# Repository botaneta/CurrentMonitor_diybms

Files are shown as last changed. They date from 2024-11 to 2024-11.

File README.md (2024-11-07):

Not tested, Modification of the original project https://github.com/pprasse/diyBMS_CurrentVoltage_ADS1115
----------

# diyBMS_CurrentVoltage_ADS1115

Isolated current and isolated voltage sensor for up to 850V & 200A based on ADS1115 and attiny1614 with isolated RS485 / MODBUS. (based on https://github.com/stuartpittaway/diyBMS-CurrentShunt)

# Current / Voltage measurement

The current measurement uses an ACS758ECB-200B hall-effect based current sensor IC.

The voltage measurement is isolated using an ACPL-C870 Precision Optically Isolated Voltage Sensor.

The analog signal from both measurements are converted using a ADS1115 16 bit ADC.

Coulomb calculation takes place in using an attiny1614 and communication uses isolated RS485 / MODBUS.

# Basis

The project is based on https://github.com/stuartpittaway/diyBMS-CurrentShunt and was created to allow using high voltage batteries for diyBMSv4.

# BOARD

The schematics and board are in the directory KiCad.

# CODE / FIRMWARE

The firmware in the directory code is losely based on Stuard Pittaway's diyBMS CurrentShunt. It uses the same MODBUS RTU registers.

## Coulomb calculation

The charge that goes in and out is calculated by sampling the current 128 times per second using the ADS1115 and measuring the time beween each sample. These are then integrated first to mA*ms (uAs) and then every second to mAh (milliamphours).

## Voltage measurement

The voltage is measured every 1 second as it's irrelevant for charge calculation but interesting for power calculation and over/undervoltage checks.

## MODBUS registers

See [MODBUS Registers.md](./code/MODBUS%20Registers.md)

Maximum compatibililty to diyBMS-CurrentShunt should be maintained to allow using the diyBMS4 ESP32 code unmodified.

Please note that due to compatibility the double registers are in mixed endian (floats compromised of 2 16bit registers in little endian, but individual 16 bit registers are big endian) BUT the 32bit integers are big endian.

Use [read-modbus.sh](./code/read-modbus.sh) ```# code/read-modbus.sh``` to read the modbus registers.

# WARNING

This is a DIY product/solution so don’t use this for safety critical systems or in any situation where there could be a risk to life.  

This board was designed to work with high DC voltages which are notoriously dangerous to work with and are a risk to life. Please make sure you have the appropriate knowledge and always use fuses specified for DC.

There is no warranty, it may not work as expected or at all.

The use of this project is done so entirely at your own risk.  It may involve electrical voltages which could kill - if in doubt, seek help.

The use of this project may not be compliant with local laws or regulations - if in doubt, seek help.

# License

This work is licensed under a Creative Commons Attribution-NonCommercial-ShareAlike 2.0 UK: England & Wales License.

https://creativecommons.org/licenses/by-nc-sa/2.0/uk/

You are free to:
* Share — copy and redistribute the material in any medium or format
* Adapt — remix, transform, and build upon the material
The licensor cannot revoke these freedoms as long as you follow the license terms.

Under the following terms:
* Attribution — You must give appropriate credit, provide a link to the license, and indicate if changes were made. You may do so in any reasonable manner, but not in any way that suggests the licensor endorses you or your use.
* Non-Commercial — You may not use the material for commercial purposes.
* ShareAlike — If you remix, transform, or build upon the material, you must distribute your contributions under the same license as the original.
* No additional restrictions — You may not apply legal terms or technological measures that legally restrict others from doing anything the license permits.

Notices:
You do not have to comply with the license for elements of the material in the public domain or where your use is permitted by an applicable exception or limitation.

No warranties are given. The license may not give you all of the permissions necessary for your intended use. For example, other rights such as publicity, privacy, or moral rights may limit how you use the material.

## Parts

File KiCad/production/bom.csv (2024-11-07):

Designator | Footprint | Quantity | Value | LCSC Part #
_143, _142, _141, _140, _139, _138, _137, _136, _135, _134, _133, _132, _131, _130, _129, _128, _127, _126, _125, _124, _123, _122, _121, _120, _119, _118, _117, _116, _115, _114, _113, _112, _111, _110, _109, _108, _107, _106, _105, _104, _103, _102, _101, _100, _99, _98, _97, _96, _95, _94, _93, _92, _91, _90, _89, _88, _87, _86, _85, _84, _83, _82, _81, _80, _79, _78, _77, _76, _75, _74, _73, _72, _71, _70, _69, _68, _67, _66, _65, _64, _63, _62, _61, _60, _59, _58, _57, _56, _55, _54, _53, _52, _51, _50, _49, _48, _47, _46, _45, _44, _43, _42, _41, _40, _39, _38, _37, _36, _35, _34, _33, _32, _31, _30, _29, _28, _27, _26, _25, _24, _23, _22, _21, _20, _19, _18, _17, _16, _15, _14, _13, _12, _11, _10, _9, _8, _7, _6, _5, _4, _3, _2, |  | 143
C1, C16, C18, C4, C7 | 0805 | 5 | 10u
C10, C8, C9 | 0805 | 3 | 100nF
C11, C12, C13, C14, C15, C17, C2, C26, C3, C5 | 0805 | 10 | 100n
C19 | 1206 | 1 | 1uF
C20 | 0805 | 1 | 100nF 100V
C21 | 0805 | 1 | 1uF
C22, C23 | 0805 | 2 | 10nF
C24 | 0805 | 1 | 3.3nF
C25 | 1210 | 1 | 47uF
C6 | 0805 | 1 | 1n
D1 | D_SMA | 1 | SMAJ5.0A
D2 | 0805 | 1 | GREEN
D3 | 0805 | 1 | RED
D4 | D_SMA | 1 | 400V 1A 1.3V @ 1A 150ns SMA
F1 | 1210 | 1 | Fuse, 0.5A
J1 | PhoenixContact_MSTBA_2,5_3-G-5,08_1x03_P5.08mm_Horizontal | 1 | Screw_Terminal_01x03
J2 | PinHeader_1x11_P2.54mm_Vertical | 1 | Conn_01x11_Pin
J3 | PhoenixContact_MC_1,5_4-G-3.5_1x04_P3.50mm_Horizontal | 1 | Screw_Terminal_01x04
J4 | Wuerth_REDCUBE-THR_WP-THRBU_74650194_THR | 1 | 9x9 PIN connector
J6 | PhoenixContact_MC_1,5_2-G-3.81_1x02_P3.81mm_Horizontal | 1 | Screw_Terminal_01x02
JP1 | SolderJumper-2_P1.3mm_Bridged_Pad1.0x1.5mm | 1 | SolderJumper_2_Bridged
L1 | L_TDK_SLF7045 | 1 | 1mH
PS1 | Converter_DCDC_Murata_MEE1SxxxxSC_THT | 1 | MEE1S0505SC
R1, R10, R11, R18, R2 | 0805 | 5 | 4k7
R12, R13 | 0805 | 2 | 330R
R14 | 0805 | 1 | 470R
R15, R17, R23, R24, R7, R8 | 0805 | 6 | 10K
R16 | 0805 | 1 | 120R
R20 | 0805 | 1 | 680k
R21 | 0805 | 1 | 150k
R22 | 0805 | 1 | 470k
R3, R4, R5 | PP | R_MELF_MMB-0207 | 0805 Compatible | 3 | 402k
R6 | PP _ R_MELF_MMB-0207 _ 0805 Compatible | 1 | 4k7
R9 | 0805 | 1 | 100K
RV1 | Potentiometer_Bourns_3296W_Vertical | 1 | 500
U1 | SSO-8_6.8x5.9mm_P1.27mm_Clearance8mm | 1 | ACPL-C870
U2 | TSSOP-10_3x3mm_P0.5mm | 1 | ADS1115IDGS
U3 | Allegro_CB_PFF | 1 | ACS758xCB-200B-PFF
U4 | SOIC-14_3.9x8.7mm_P1.27mm | 1 | ATtiny1614-SS
U5 | SOIC-16W_7.5x10.3mm_P1.27mm | 1 | ADM2483xRW
U6 | MSOP-8_3x3mm_P0.65mm | 1 | LM5009A

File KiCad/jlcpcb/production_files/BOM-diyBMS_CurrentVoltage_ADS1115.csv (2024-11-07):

Comment | Designator | Footprint | LCSC
100K | R9 | R_0805_2012Metric | C103905
ACPL-C870 | U1 | SSO-8_6.8x5.9mm_P1.27mm_Clearance8mm | C1346335
1uF | C19 | C_1206_3216Metric | C13832
ACS758xCB-200B-PFF | U3 | Allegro_CB_PFF | C163288
10nF | C22,C23 | C_0805_2012Metric | C1710
10K | R15,R17,R23,R24,R7,R8 | R_0805_2012Metric | C17414
120R | R16 | R_0805_2012Metric | C17437
150k | R21 | R_0805_2012Metric | C17470
330R | R12,R13 | R_0805_2012Metric | C17630
4k7 | R1,R10,R11,R18,R2 | R_0805_2012Metric | C17673
470k | R22 | R_0805_2012Metric | C17709
470R | R14 | R_0805_2012Metric | C17710
680k | R20 | R_0805_2012Metric | C17797
GREEN | D2 | LED_0805_2012Metric | C2297
1uF | C21 | C_0805_2012Metric | C28323
10u | C1,C16,C18,C4,C7 | C_0805_2012Metric | C2932476
ADS1115IDGS | U2 | TSSOP-10_3x3mm_P0.5mm | C37593
ADM2483xRW | U5 | SOIC-16W_7.5x10.3mm_P1.27mm | C386280
LM5009A | U6 | MSOP-8_3x3mm_P0.65mm | C477978
ATtiny1614-SS | U4 | SOIC-14_3.9x8.7mm_P1.27mm | C481364
100nF | C10,C8,C9 | C_0805_2012Metric | C49678
MEE1S0505SC | PS1 | Converter_DCDC_Murata_MEE1SxxxxSC_THT | C5183119
3.3nF | C24 | C_0805_2012Metric | C53175
500 | RV1 | Potentiometer_Bourns_3296W_Vertical | C69564
100nF 100V | C20 | C_0805_2012Metric | C696367
Fuse, 0.5A | F1 | Fuse_1210_3225Metric | C720079
47uF | C25 | C_1210_3225Metric | C77101
RED | D3 | LED_0805_2012Metric | C84256
400V 1A 1.3V @ 1A 150ns SMA | D4 | D_SMA | C85103
1mH | L1 | L_TDK_SLF7045 | C91523

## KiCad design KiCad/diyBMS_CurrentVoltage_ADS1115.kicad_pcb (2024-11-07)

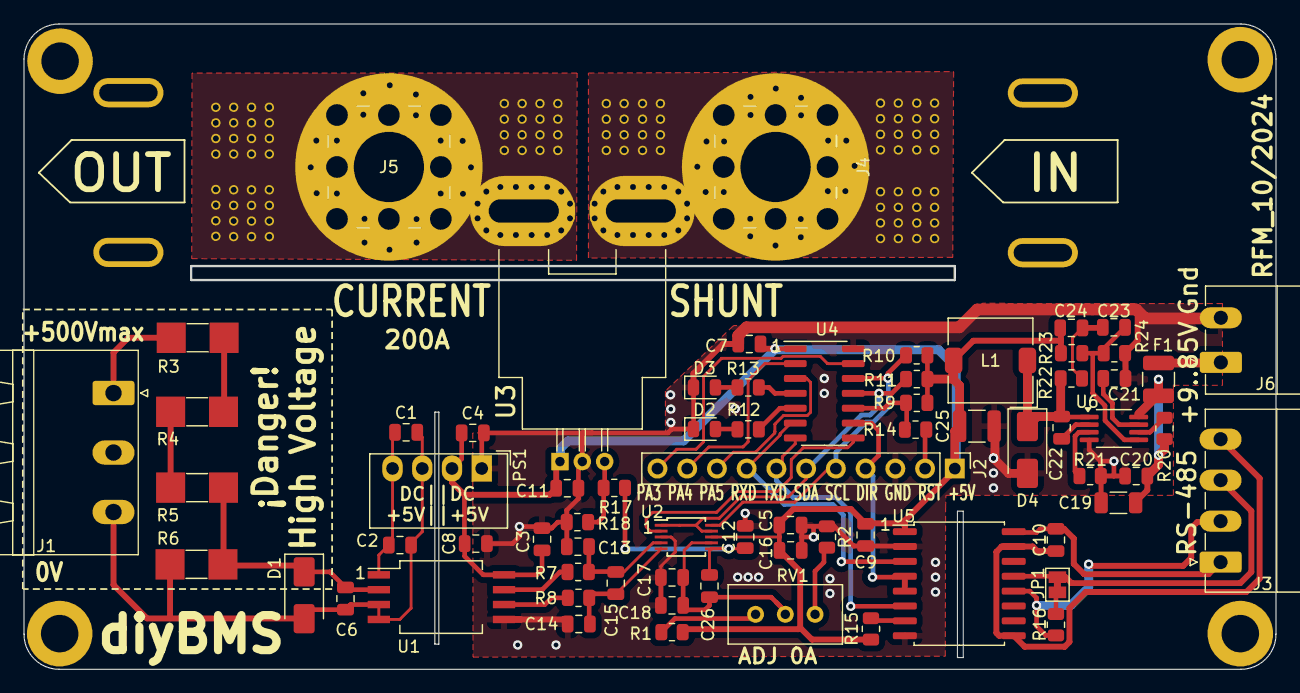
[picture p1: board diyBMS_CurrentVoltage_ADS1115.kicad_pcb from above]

Board: 2 copper layers, 106.9 x 55.1 mm, 70 parts (0 on the bottom side), 49 nets.

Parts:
C1, C4, C7, C16, C18: 10u; C_0805_2012Metric
C2, C3, C5, C11, C12, C13, C14, C15, C17, C26: 100n; C_0805_2012Metric
C6: 1n; C_0805_2012Metric
C8, C9, C10: 100nF; C_0805_2012Metric
C19: 1uF; C_1206_3216Metric
C20: 100nF 100V; C_0805_2012Metric
C21: 1uF; C_0805_2012Metric
C22, C23: 10nF; C_0805_2012Metric
C24: 3.3nF; C_0805_2012Metric
C25: 47uF; C_1210_3225Metric
D1: SMAJ5.0A; D_SMA
D2: GREEN; LED_0805_2012Metric
D3: RED; LED_0805_2012Metric
D4: 400V 1A 1.3V @ 1A 150ns SMA; D_SMA
F1: Fuse, 0.5A; Fuse_1210_3225Metric
J1: Screw_Terminal_01x03; PhoenixContact_MSTBA_2,5_3-G-5,08_1x03_P5.08mm_Horizontal
J2: Conn_01x11_Pin; PinHeader_1x11_P2.54mm_Vertical
J3: Screw_Terminal_01x04; PhoenixContact_MC_1,5_4-G-3.5_1x04_P3.50mm_Horizontal
J4, J5: 9x9 PIN connector; Wuerth_REDCUBE-THR_WP-THRBU_74650194_THR
J6: Screw_Terminal_01x02; PhoenixContact_MC_1,5_2-G-3.81_1x02_P3.81mm_Horizontal
JP1: SolderJumper_2_Bridged; SolderJumper-2_P1.3mm_Bridged_Pad1.0x1.5mm
L1: 1mH; L_TDK_SLF7045
PS1: MEE1S0505SC; Converter_DCDC_Murata_MEE1SxxxxSC_THT
R1, R2, R10, R11, R18: 4k7; R_0805_2012Metric
R3, R4, R5: 402k; PP | R_MELF_MMB-0207 | 0805 Compatible
R6: 4k7; PP _ R_MELF_MMB-0207 _ 0805 Compatible
R7, R8, R17, R23, R24: 10k; R_0805_2012Metric
R9: 100K; R_0805_2012Metric
R12, R13: 330R; R_0805_2012Metric
R14: 470R; R_0805_2012Metric
R15: 10K; R_0805_2012Metric
R16: 120R; R_0805_2012Metric
R20: 680k; R_0805_2012Metric
R21: 150k; R_0805_2012Metric
R22: 470k; R_0805_2012Metric
RV1: 500R; Potentiometer_Bourns_3296W_Vertical
U1: ACPL-C870; SSO-8_6.8x5.9mm_P1.27mm_Clearance8mm
U2: ADS1115IDGS; TSSOP-10_3x3mm_P0.5mm
U3: ACS758xCB-200B-PFF; Allegro_CB_PFF
U4: ATtiny1614-SS; SOIC-14_3.9x8.7mm_P1.27mm
U5: ADM2483xRW; SOIC-16W_7.5x10.3mm_P1.27mm
U6: LM5009A; MSOP-8_3x3mm_P0.65mm

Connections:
+5V: C3.1, C4.1, C5.1, C7.1, C8.1, C9.1, C11.1, C16.2, C24.1, C25.2, J2.1, L1.2, PS1.2 (+Vin), R1.2, R9.2, R10.1, R11.1, R15.1, R23.1, U1.8 (VDD2), U2.8 (VDD), U3.1 (VCC), U4.1 (VCC), U5.1 (VDD1)
+5VP: C1.1, C2.1, PS1.4 (+Vout), U1.1 (VDD1)
A: J3.2, R16.2, U5.12 (A)
ALERT: U2.2 (ALERT/RDY), U4.8 (PB1)
B: J3.3, JP1.2 (B), U5.13 (B)
GND: C3.2, C4.2, C5.2, C7.2, C8.2, C9.2, C11.2, C12.2, C13.1, C14.2, C16.1, C17.2, C18.2, C19.2, C20.2, C21.1, C25.1, D2.1 (K), D3.1 (K), D4.2 (A), J2.3, J6.2, PS1.1 (-Vin), R2.2, R18.2, R21.2, R24.2, U1.5 (GND2), U2.3 (GND), U3.2 (GND), U4.14 (GND), U5.2 (GND1), U5.8 (GND1), U6.4 (RTN)
GND1: C1.2, C2.2, C6.2, D1.2 (A2), J1.3, PS1.3 (-Vout), R6.2, U1.3 (IN-), U1.4 (GND1)
GND2: C10.1, J3.4, U5.9 (GND2), U5.15 (GND2)
unnamed: C23.2, C24.2, R22.2
unnamed: C6.1, D1.1 (A1), R5.2, R6.1, U1.2 (IN)
unnamed: D2.2 (A), R12.1
unnamed: D3.2 (A), R13.1
unnamed: C22.2, D4.1 (K), L1.1, R22.1, U6.1 (SW)
unnamed: J1.1, R3.1
unnamed: J2.2, R14.1
unnamed: J4.1, U3.4 (IP+)
unnamed: J5.1, U3.5 (IP-)
unnamed: F1.2, J6.1
unnamed: JP1.1 (A), R16.1
unnamed: R1.1, RV1.1
unnamed: R2.1, RV1.3
unnamed: R3.2, R4.1
unnamed: R4.2, R5.1
unnamed: R7.1, U1.7 (OUT+)
unnamed: R8.1, U1.6 (OUT-)
unnamed: C13.2, C15.2, R7.2, U2.4 (AIN0)
unnamed: C14.1, C15.1, R8.2, U2.5 (AIN1)
unnamed: C12.1, C26.2, R17.1, U2.6 (AIN2)
unnamed: C17.1, C18.1, C26.1, RV1.2, U2.7 (AIN3)
unnamed: R17.2, R18.1, U3.3 (VIOUT)
unnamed: R15.2, U5.7 (PV)
unnamed: C22.1, U6.2 (BST)
unnamed: C23.1, R23.2, R24.1, U6.5 (FB)
unnamed: R21.1, U6.3 (RCL)
unnamed: R20.2, U6.6 (Rt/SD)
unnamed: C21.2, U6.7 (VCC)
unnamed: C19.1, C20.1, F1.1, R20.1, U6.8 (VIN)
PA3: J2.11, U4.13 (PA3)
PA4: J2.10, U4.2 (PA4)
PA5: J2.9, U4.3 (PA5)
PA6: R13.2, U4.4 (PA6)
PA7: R12.2, U4.5 (PA7)
RESET: R9.1, R14.2, U4.10 (~RESET/PA0)
RXD: J2.8, U4.6 (PB3), U5.3 (RxD)
SCL: J2.5, R10.2, U2.10 (SCL), U4.12 (PA2)
SDA: J2.6, R11.2, U2.1 (ADDR), U2.9 (SDA), U4.11 (PA1)
TXD: J2.7, U4.7 (PB2), U5.6 (TxD)
VDD2: C10.2, J3.1, U5.16 (VDD2)
XDIR: J2.4, U4.9 (PB0), U5.4 (~RE), U5.5 (DE)

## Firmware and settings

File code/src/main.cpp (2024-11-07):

/*
 ____  ____  _  _  ____  __  __  ___    _  _  __
(  _ \(_  _)( \/ )(  _ \(  \/  )/ __)  ( \/ )/. |
 )(_) )_)(_  \  /  ) _ < )    ( \__ \   \  /(_  _)
(____/(____) (__) (____/(_/\/\_)(___/    \/   (_)

DIYBMS V4.0
ISOLATED CURRENT & VOLTAGE MONITORING SYSTEM BASEDO ON ADS1115 / ACS758 / ACPL-C870

(c)2023 Patrick Prasse

based on https://github.com/stuartpittaway/diyBMS-CurrentShunt
(c)2021 Stuart Pittaway

COMPILE THIS CODE USING PLATFORM.IO

LICENSE
Attribution-NonCommercial-ShareAlike 2.0 UK: England & Wales (CC BY-NC-SA 2.0 UK)
https://creativecommons.org/licenses/by-nc-sa/2.0/uk/

* Non-Commercial — You may not use the material for commercial purposes.
* Attribution — You must give appropriate credit, provide a link to the license, and indicate if changes were made.
  You may do so in any reasonable manner, but not in any way that suggests the licensor endorses you or your use.
* ShareAlike — If you remix, transform, or build upon the material, you must distribute your
  contributions under the same license as the original.
* No additional restrictions — You may not apply legal terms or technological measures
  that legally restrict others from doing anything the license permits.

** COMMERCIAL USE AND RESALE PROHIBITED **

*/

// ATTINY1614 (tinyAVR® 1-series of microcontrollers)
// http://ww1.microchip.com/downloads/en/DeviceDoc/ATtiny1614-data-sheet-40001995A.pdf

// MODBUS Protocol
// https://www.ni.com/en-gb/innovations/white-papers/14/the-modbus-protocol-in-depth.html

#if !defined(MODBUSDEFAULTBAUDRATE)
#error MODBUSDEFAULTBAUDRATE must be defined
#endif
#if !defined(MODBUSBASEADDRESS)
#error MODBUSBASEADDRESS must be defined
#endif
#if !defined(MODBUSSERIALCONFIG)
#error MODBUSSERIALCONFIG must be defined
#endif

#include <Arduino.h>
#include <avr/sleep.h>
#include <avr/power.h>
#include <avr/wdt.h>
#include <Wire.h>
#include <EEPROM.h>

#include <FastCRC.h>
#include "debug.h"
#include "ads1115.h"


FastCRC16 CRC16;

#include "main.h"
#include "settings.h"

#include "EmbeddedFiles_Defines.h"

#ifndef SERIALDEBUG
#include "SimpleModbusSlave.h"
#endif

#ifdef SERIALDEBUG
uint32_t lastDebugOutput = 0;
#endif

const uint16_t loop_delay_ms = 2000;

uint32_t milliamphour_out_lifetime = 0;
uint32_t milliamphour_in_lifetime = 0;

uint32_t daily_milliamphour_out = 0;
uint32_t daily_milliamphour_in = 0;

uint32_t milliamphour_out = 0;
uint32_t milliamphour_in = 0;

uint32_t milliamphour_out_offset = 0;
uint32_t milliamphour_in_offset = 0;

uint16_t ModBusBaudRate = MODBUSDEFAULTBAUDRATE;

uint8_t ModbusSlaveAddress = MODBUSBASEADDRESS;

volatile bool config_dirty = false;

uint8_t max_soc_reset_counter = 0;
uint8_t soc_reset_counter = 0;
int32_t last_charge_coulombs = 0;

unsigned long timer = 0;

eeprom_regs registers;

volatile bool wdt_triggered = false;
volatile uint16_t wdt_triggered_count;

void DefaultConfig();


uint16_t CalculateSOC()
{
  double milliamphour_in_scaled = ((double)milliamphour_in / 100.0) * registers.charge_efficiency_factor;
  double milliamphour_batterycapacity = 1000.0 * (uint32_t)registers.batterycapacity_amphour;
  double difference = milliamphour_in_scaled - milliamphour_out;

  double answer = 100 * (difference / milliamphour_batterycapacity);
  if (answer < 0)
  {
    // We have taken more out of the battery than put in, so must be zero SoC (or more likely out of calibration)
    return 0;
  }

  // Add a hard upper limit 655.0%
  if (answer > 655.0)
  {
    answer = 655.0;
  }

  // Store result as fixed point decimal
  uint16_t SOC = 100 * answer;

  return SOC;
}

void ConfigurePorts()
{
  // PA1 = SDA
  // PA2 = SCL
  // PA3 = UNUSED
  // PA4 = UNUSED
  // PA5 = RELAY OUTPUT
  // PA6 = RED LED
  // PA7 = GREEN LED

  // Set pins as Outputs (other pins are inputs)
  PORTA.DIR = GREENLED_PIN_BITMAP | REDLED_PIN_BITMAP | RELAY_PIN_BITMAP;

  // Relay off by default
  PORTA.OUTCLR = RELAY_PIN_BITMAP;

  // Set Port B digital outputs
  // PB0 = XDIR (RS485 transmit enable)
  // PB1 = ALERT
  // PB2 = TX (has to be set as output on tiny1614)
  // PB3 = RX
  // Set pins as Outputs (other pins are inputs)
  PORTB.DIR = PIN0_bm | PIN2_bm;

  PORTB.OUTSET = PIN2_bm; // TX is high

  USART0.CTRLB = USART_RXEN_bm | USART_TXEN_bm; // enable rx and tx
  // Enable interrupts
  sei();
}

void RedLED(bool value)
{
  if (value)
  {
    PORTA.OUTSET = REDLED_PIN_BITMAP;
  }
  else
  {
    PORTA.OUTCLR = REDLED_PIN_BITMAP;
  }
}

void GreenLED(bool value)
{
  if (value)
  {
    PORTA.OUTSET = GREENLED_PIN_BITMAP;
  }
  else
  {
    PORTA.OUTCLR = GREENLED_PIN_BITMAP;
  }
}

void EnableWatchdog()
{
  wdt_triggered = false;

  // Enter protection mode
  CCP = 0xD8;

  // 8 seconds
  WDT.CTRLA = WDT_PERIOD_enum::WDT_PERIOD_8KCLK_gc;

  wdt_reset();
}

/*
void DisableSerial0TX()
{
  //On tiny1614 this saves about 10mA of current
  USART0.CTRLB &= ~(USART_TXEN_bm); // Transmitter Enable bit mask.
}

void EnableSerial0TX()
{
  //When the transmitter is disabled, it will no longer override the TXD pin, and the pin
  //direction is automatically set as input by hardware, even if it was configured as output by the user
  //PB2 as OUTPUT
  PORTB.DIRSET = PIN2_bm;
  USART0.CTRLB |= USART_TXEN_bm; // Transmitter Enable bit mask.
}
*/

void WatchdogTriggered()
{
  // This is the watchdog timer - something went wrong and no serial activity received in over 8 seconds
  wdt_triggered = true;
  wdt_triggered_count++;
}

// pattern is a 32bit pattern to "play" on the RED LED to indicate failure
void __attribute__((noreturn)) blinkPattern(uint32_t pattern)
{
  #ifdef SERIALDEBUG
  Serial.print("blinkPattern=");
  Serial.println(pattern);
  #endif

  // Show the error 4 times
  for (size_t x = 0; x < 4; x++)
  {
    uint32_t p = pattern;

    // Loop through the 32 bits - takes 1024ms in total
    for (size_t i = 0; i < 32; i++)
    {
      wdt_reset();
      if (p & 1)
      {
        RedLED(true);
      }
      else
      {
        RedLED(false);
      }
      p >>= 1;

      // Give user enough time to count the pulses
      delay(200);
    }

    // Switch off LED and wait half second before repeating
    RedLED(false);
    for (size_t i = 0; i < 40; i++)
    {
      wdt_reset();
      delay(50);
    }
  }

  // Both LEDs on whilst we wait for WDT
  RedLED(true);
  GreenLED(true);

  // Finally just hang - this will trigger the watchdog causing a reboot
  delay(100000);
}

// Sets SOC by setting "fake" in/out amphour counts
// value=8212 = 82.12%
void SetSOC(uint16_t value)
{
  // Assume battery is fully charged
  milliamphour_in = 1000 * (uint32_t)registers.batterycapacity_amphour;
  // And we have consumed this much...
  milliamphour_out = (1.0 - ((float)value / 10000.0)) * milliamphour_in;

  // Zero out readings using the offsets
  milliamphour_out_offset = milliamphour_out;
  milliamphour_in_offset = milliamphour_in;
}

void DefaultConfig()
{
    // Clear structure
    memset(&registers, 0, sizeof(eeprom_regs));
    registers.git_version_b1 = GIT_VERSION_B1;
    registers.git_version_b2 = GIT_VERSION_B2;


    // Defaults for battery capacity/voltages
    registers.batterycapacity_amphour = 280;
    registers.fully_charged_voltage = 3.50 * 16;
    registers.tail_current_amps = 20;
    registers.charge_efficiency_factor = 99.5;

    // ACS758 _hall_ sensor produces +2.0V at +200A
    registers.shunt_max_current = 200;
    registers.shunt_millivolt = 2000;
    registers.RSHUNT = (double)registers.shunt_millivolt / ((double)registers.shunt_max_current*1000);

    registers.R_SHUNT_CAL = 0;

    // Not supported and not needed for ACS758
    registers.R_SHUNT_TEMPCO = 0;

    registers.bus_overcurrent = 100;
    registers.bus_undercurrent = -100;
    // 850volt max
    registers.bus_overvoltage = 57.6;
    registers.bus_undervoltage = 41.6;
    registers.temp_limit = 60.0;

    // Default Power limit = 5kW
    registers.power_limit = 5000.0;

    bitflags defaults_bitflags;
    defaults_bitflags.uint16 = 0;
    defaults_bitflags.bits.relay_trigger_pol = 1;
    defaults_bitflags.bits.relay_trigger_busul = 1;
    defaults_bitflags.bits.relay_trigger_busol = 1;
    defaults_bitflags.bits.relay_trigger_ucurr = 1;
    defaults_bitflags.bits.relay_trigger_ocurr = 1;
    defaults_bitflags.bits.relay_trigger_tmpol = 1;
    registers.bitflags.uint16 = defaults_bitflags.uint16;
    DEBUG_PRINTLN(registers.bitflags.uint16);
}

void SaveConfig()
{
  WriteConfigToEEPROM((uint8_t *)&registers, sizeof(eeprom_regs));
}

bool SetRegister(uint16_t address, uint16_t value)
{
    static DoubleUnionType newvalue;

    switch (address)
    {
        case 4:
        case 6:
        //|40022|Fully charged voltage (4 byte double)
        case 21:
        //|40024|Tail current (Amps) (4 byte double)
        case 23:
        // Temperature limit (signed int16)
        case 29:
        // Bus Overvoltage (overvoltage protection)
        case 31:
        // BusUnderVolt
        case 33:
        // Shunt Over Voltage Limit (current limit)
        case 35:
        case 37:
        {
          // Set word[0] in preperation for the next register to be written
          newvalue.word[0] = value;
          break;
        }

        case 9:
        {
          // Bit flags
          setBitFlags(value);
          registers.bitflags.uint16 = value;
          break;
        }

        // Allow reset of daily AH counters to ZERO
        case 12:
        case 13:
        {
          // Daily milliamphour_out (4 byte unsigned long uint32_t)
          daily_milliamphour_out = 0;
          break;
        }
        case 14:
        case 15:
        {
          // Daily milliamphour_in (4 byte  unsigned long uint32_t)
          daily_milliamphour_in = 0;
          break;
        }

        case 18:
        {
          registers.shunt_max_current = value;
          set_mA_per_mV((uint32_t)registers.shunt_max_current*1000/(uint32_t)registers.shunt_millivolt);
          break;
        }
        case 19:
        {
          // Register 40020
          registers.shunt_millivolt = value;
          set_mA_per_mV((uint32_t)registers.shunt_max_current*1000/(uint32_t)registers.shunt_millivolt);
          break;
        }

        case 20:
        {
          //|40021|Battery Capacity (ah)  (unsigned int16)
          registers.batterycapacity_amphour = value;
          break;
        }
        case 22:
        {
          //|40023|Fully charged voltage
          newvalue.word[1] = value;
          registers.fully_charged_voltage = newvalue.dblvalue;
          break;
        }

        case 24:
        {
          //|40025|Tail current (Amps)
          newvalue.word[1] = value;
          registers.tail_current_amps = newvalue.dblvalue;
          break;
        }
        case 25:
        {
          //|40026|Charge efficiency factor % (unsigned int16) (scale x100 eg. 10000 = 100.00%, 9561 = 95.61%)
          registers.charge_efficiency_factor = ((double)value) / 100.0;
          break;
        }
        case 26:
        {
          //|40027|State of charge % (unsigned int16) (scale x100 eg. 10000 = 100.00%, 8012 = 80.12%, 100 = 1.00%)
          // Change SOC by altering the amp hour counters
          SetSOC(value);
          break;
        }
        case 27:
        {
          // Register 40028
          // SHUNT_CAL register
          registers.R_SHUNT_CAL = value;
          break;
        }
        case 28:
        {
          // temperature limit
          // Case unsigned to int16 to cope with negative temperatures
          registers.temp_limit = value;
          break;
        }
        case 30:
        {
          // Bus Overvoltage (overvoltage protection).
          // Unsigned representation, positive value only. Conversion factor: 3.125 mV/LSB.
          newvalue.word[1] = value;
          registers.bus_overvoltage = newvalue.dblvalue;
          break;
        }
        case 32:
        {
          // Bus under voltage
          newvalue.word[1] = value;
          registers.bus_undervoltage = newvalue.dblvalue;
          break;
        }
        case 34:
        {
          // Shunt Over Voltage Limit (current limit)
          newvalue.word[1] = value;
          registers.bus_overcurrent = newvalue.dblvalue;

          break;
        }

        case 36:
        {
          // Shunt UNDER Voltage Limit (under current limit)
          newvalue.word[1] = value;
          registers.bus_undercurrent = newvalue.dblvalue;
          break;
        }

        case 38:
        {
          // Shunt Over POWER LIMIT
          newvalue.word[1] = value;
          registers.power_limit = newvalue.dblvalue;
          break;
        }

        case 39:
        {
          // Shunt Temperature Coefficient
          registers.R_SHUNT_TEMPCO = value;
          break;
        }

        case 45:
        {
          // Watchdog timer trigger count (like error counter)
          wdt_triggered_count = value;
          break;
        }

        default:
        {
          return false;
          break;
        }
    }

    // Rather than writing to EEPROM on every register change (there could be several)
    // mark the configuration as "dirty" and the loop() will write the config to EEPROM
    // in a few seconds time
    config_dirty = true;

    return true;
}

void setup()
{

  // Did we have a watchdog reboot?
  if (RSTCTRL.RSTFR & RSTCTRL_WDRF_bm)
  {
    // Must be first line of code
    WatchdogTriggered();
  }
  else
  {
    wdt_triggered_count = 0;
  }

  ConfigurePorts();

  RedLED(false);
  GreenLED(false);
  EnableWatchdog();

  // Serial uses PB2/PB3 and PB0 for XDIR
  Serial.begin(ModBusBaudRate, MODBUSSERIALCONFIG);
  // leave XDIR on in every case as we can debug over RS485 using the compile define SERIALDEBUG
  // 0x01= Enables RS-485 mode with control of an external line driver through a dedicated Transmit Enable (TE) pin.
  USART0.CTRLA |= USART_RS485_EXT_gc;

  // Disable RS485 receiver (debug!)
  #ifdef SERIALDEBUG
  PORTB.OUTSET = PIN0_bm;
  PORTB.PIN0CTRL = 0;
  #endif



  if (ReadConfigFromEEPROM((uint8_t *)&registers, sizeof(eeprom_regs)) == false || 
    registers.git_version_b1 != GIT_VERSION_B1 ||
    registers.git_version_b2 != GIT_VERSION_B2 )
  {
    // Flash RED led 5 times to indicate facory reset
    for (size_t i = 0; i < 5; i++)
    {
      RedLED(true);
      delay(200);
      RedLED(false);
      delay(200);
    }
    DEBUG_PRINTLN("INVALID_EEPROM");

    // EEPROM is invalid, so apply "factory" defaults
    DefaultConfig();

    config_dirty = true;
  }


  set_mA_per_mV((uint32_t)registers.shunt_max_current*1000/(uint32_t)registers.shunt_millivolt);

  DEBUG_PRINTLN("NORMAL_BOOTUP");
  if( wdt_triggered )
  {
    DEBUG_PRINTLN("wdt_triggered");
  }
  else
  {
    DEBUG_PRINTLN("NOT wdt_triggered");
  }


  // Flash LED to indicate normal boot up
  for (size_t i = 0; i < 6; i++)
  {
    GreenLED(true);
    if (wdt_triggered)
    {
      RedLED(true);
    }
    delay(50);
    GreenLED(false);
    if (wdt_triggered)
    {
      RedLED(false);
    }
    delay(150);
  }


  uint32_t status = ads1115_setup();
  DEBUG_PRINT("ads1115_setup result=");
  DEBUG_PRINTLN(status);
  if( status )
  {
    blinkPattern(status);
    return;
  }

  setBitFlags(registers.bitflags.uint16);

  DEBUGKV("----------- registers.bitflags.uint16=", registers.bitflags.uint16);
  DEBUGKV("----------- bitFlags()=", bitFlags());

  wdt_triggered = false;

#ifndef SERIALDEBUG
  modbus_configure(&Serial, ModBusBaudRate);
#endif

/*
  // Default SOC% at 60%
  uint16_t soc = 6000;

  // We apply a "guestimate" to SoC based on voltage - not really accurate, but somewhere to start
  // only applicable to 24V/48V (16S) setups. These voltages should be the unloaded (no current flowing) voltage.
  // Assumption that its LIFEPO4 cells we are using
  double v = BusVoltage();
  // PP TODO: does not work yet, needs to be measured first


  if (v > 20 && v < 30)
  {
    // Scale up to use the 48V scale
    v = v * 2;
  }

  if (v > 40 && v < 60)
  {
    // 16S LIFEPO4...
    if (v >= 40.0)
      soc = 500;
    if (v >= 48.0)
      soc = 900;
    if (v >= 50.0)
      soc = 1400;
    if (v >= 51.2)
      soc = 1700;
    if (v >= 51.6)
      soc = 2000;
    if (v >= 52.0)
      soc = 3000;
    if (v >= 52.4)
      soc = 4000;
    if (v >= 52.8)
      soc = 7000;
    if (v >= 53.2)
      soc = 9000;
  }

  SetSOC(soc);
*/

  // Reset the daily counters
  daily_milliamphour_in = 0;
  daily_milliamphour_out = 0;
}


double TemperatureLimit()
{
  return registers.temp_limit;
}

ISR(PORTB_PORT_vect)
{
  uint8_t flags = PORTB.INTFLAGS;
  PORTB.INTFLAGS = flags; // clear flags

  if (flags && PIN1_bm)
  {
    ads1115_isr();
  }
}
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
void loop()
{
    wdt_reset();

/*
    //Enable interrupts
    sei();
    //Start frame detection
    USART0.CTRLB |= USART_SFDEN_bm;

    //Switch off TX, saves current
    //DisableSerial0TX();

    if (!Serial.available())
    {
      //Enter sleep
      set_sleep_mode(SLEEP_MODE_STANDBY);
      sleep_enable();
      sleep_cpu();

      //Snoring can be heard at this point....
      sleep_disable();
    }
*/

    ads1115_loop();

    if (!haveAlert())
    {
      RedLED(false);
      PORTA.OUTCLR = RELAY_PIN_BITMAP;
    }
    else
    {
      // Turn relay on/off
      if (relayOn())
      {
        PORTA.OUTSET = RELAY_PIN_BITMAP;
      }
      else
      {
        PORTA.OUTCLR = RELAY_PIN_BITMAP;
      }
    }

  #ifndef SERIALDEBUG
  modbus_update();
  #else
  #if 0
  if( (millis()-lastDebugOutput) > 10000 )
  {
    lastDebugOutput = millis();
    for(uint16_t reg=0; reg<=45; reg++ )
    {
      uint16_t result;
      ReadHoldingRegister(reg, &result);
    }
  }
  #endif
  #endif


  if (millis() > timer)
  {
    if (config_dirty)
    {
      SaveConfig();
      config_dirty = false;
    }

    RedLED(true);

    // Do it again in X seconds
    timer = millis() + loop_delay_ms;

    double voltage = BusVoltage();
    double current;

    DEBUGKV("voltage=",voltage);
    DEBUGKV("Current()=",Current());
    DEBUGKV("Power()=",Power());
    DEBUGKV("registers.bitflags.uint16=", registers.bitflags.uint16);
    DEBUGKV("bitFlags()=", bitFlags());

    // Now to test if we need to reset SOC to 100% ?
    // Check if voltage is over the fully_charged_voltage and current UNDER tail_current_amps
    if (voltage > registers.fully_charged_voltage && (current=Current()) > 0 && current < registers.tail_current_amps)
    {
      DEBUG_PRINTLN("-----------SOC RESET--------");

      // Battery has reached fully charged so wait for time counter
      soc_reset_counter++;

      // Test if counter has reached 3 minutes, indicating fully charge battery
      if (soc_reset_counter >= ((3 * 60) / (loop_delay_ms / 1000)))
      {
        // Now we reset the SOC, by clearing the registers, at this point SOC returns to 100%

        // This does have an annoying "feature" of clearing down todays Ah counts :-(
        // TODO: FIX THIS - probably need a set of shadow variables to hold the internal SOC and AH counts
        //                  but then when/how do we reset the Ah counts?

        max_soc_reset_counter = soc_reset_counter;
//        ResetChargeEnergyRegisters();
        last_charge_coulombs = 0;
        soc_reset_counter = 0;
        SetSOC(10000);
      }
    }
    else
    {
      // Voltage or current is out side of monitoring limits, so reset timer count
      soc_reset_counter = 0;
    }

    DEBUGKV("CalculateSOC()=",CalculateSOC());

    if (!haveAlert())
    {
      // Turn LED off if alert is not active
      RedLED(false);
    } // end if

  } // end if
}

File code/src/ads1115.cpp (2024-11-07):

/*
ADS1115 glue code for ACS758 current sensor and ACPL-C870 isolated voltage measurement IC

(c)2023 Patrick Prasse

LICENSE
Attribution-NonCommercial-ShareAlike 2.0 UK: England & Wales (CC BY-NC-SA 2.0 UK)
https://creativecommons.org/licenses/by-nc-sa/2.0/uk/

* Non-Commercial — You may not use the material for commercial purposes.
* Attribution — You must give appropriate credit, provide a link to the license, and indicate if changes were made.
  You may do so in any reasonable manner, but not in any way that suggests the licensor endorses you or your use.
* ShareAlike — If you remix, transform, or build upon the material, you must distribute your
  contributions under the same license as the original.
* No additional restrictions — You may not apply legal terms or technological measures
  that legally restrict others from doing anything the license permits.
*/

#include <util/atomic.h>
#include <ADS1115_lite.h>
#include "debug.h"
#include "ads1115.h"
#include "main.h"




uint32_t lastVoltage_mV = 0;
int32_t lastCurrent_mA = 0;

uint32_t timeLastCurrentMeasurement = 0;
uint32_t timeLastVoltageMeasurement = 0;

uint32_t lastCurrentIntegrationMillis = 0;
int32_t integrated_mA_ms = 0;

bitflags current_bitflags;

extern uint32_t milliamphour_out_lifetime;
extern uint32_t milliamphour_in_lifetime;

extern uint32_t daily_milliamphour_out;
extern uint32_t daily_milliamphour_in;

extern uint32_t milliamphour_out;
extern uint32_t milliamphour_in;

extern uint32_t milliamphour_out_offset;
extern uint32_t milliamphour_in_offset;

extern eeprom_regs registers;

extern void __attribute__((noreturn)) blinkPattern(uint32_t pattern);

#define ADS1115_MODE_VOLTAGE 1
#define ADS1115_MODE_CURRENT 2

uint32_t mA_per_mV = 100;

/**
 * The sampling mode (current/voltage) we just set. If not the same as ads1115_mode the next result at ISR is thrown away and ads1115_mode is set
 */
uint8_t ads1115_pending_mode = 0;

/**
 * The actual sampling mode
 */
uint8_t ads1115_mode = 0;

volatile bool ads1115_rdy = false;

ADS1115_lite ads;

bool ads1115_setupContinuousAmpereSampling();
bool ads1115_setupVoltageSampling();
void integrate_mAms_to_mAh();

bool i2c_write16bitRegister(const uint8_t address, const uint8_t inareg, const uint16_t data)
{
  Wire.beginTransmission(address);
  Wire.write(inareg);
  Wire.write((uint8_t)(data >> 8)); // Write the first (MSB) byte
  Wire.write((uint8_t)data);        // and then the second byte
  uint8_t result = Wire.endTransmission();

  // Delay after making a write to INA chip
  delayMicroseconds(10);

  return result == 0;
}

bool set_mA_per_mV(uint32_t set_mA_per_mV)
{
    mA_per_mV = set_mA_per_mV;
    return true;
}

uint32_t ads1115_setup()
{
    // for internal temperature measurement
    // https://onlinedocs.microchip.com/pr/GUID-C541EA24-5EC3-41E5-9648-79068F9853C0-en-US-3/index.html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
/*
    VREF.CTRLA = VREF_ADC0REFSEL_1V1_gc;
    ADC0.CTRLC = ADC_REFSEL_INTREF_gc;  // SAMPCAP 0
    ADC0.MUXPOS = ADC_MUXPOS_TEMPSENSE_gc;
    ADC0.CTRLD = ADC_INITDLY_DLY32_gc;
    ADC0.SAMPCTRL = ADC_ACC32;
*/
    analogReference(INTERNAL1V1);


    Wire.begin();
    // Change TWI pins to use PA1/PA2 and not PB1/PB0
    Wire.swap(1);
    // Use fast i2c
    Wire.setClock(400000);

    ATOMIC_BLOCK(ATOMIC_RESTORESTATE)
    {
        // ALARM PIN
        PORTB.DIRCLR = PIN1_bm;
        PORTB.PIN1CTRL = PORT_PULLUPEN_bm | PORT_ISC_enum::PORT_ISC_FALLING_gc;
    }

    ads1115_rdy = false;

    ads = ADS1115_lite(ADS1115address);
    if( !ads.testConnection() )
    {
        return err_ADS1115_testConnection;
    }

    ads.lowThreshold(0);
    ads.highThreshold(0xffff);

    ads1115_setupVoltageSampling();

    return 0;
}

/**
 * set ADS1115 to continuous Ampere sampling
 * 
 * ACS758 - 200B on AIN2; Vcc/2 on AIN3
 * * ACS758 - 200B output with 0 Amps = Vcc/2 = 2.5V | +200 Amps = Vcc | -200 Amps = 0V
 * 
 * This means that it makes sense to sample the differential between AIN2 and AIN3 (Vcc/2)
 * --> so with +200A we have 2.5V differential
 * --> with 0A we have 0V differential
 * --> with -200A we have -2.5V differential
*/
bool ads1115_setupContinuousAmpereSampling()
{
    // differential AIN2(input)<->AIN3(Vcc)
    ads.setMux(ADS1115_REG_CONFIG_MUX_DIFF_2_3);
    ads.setSampleRate(ADS1115_REG_CONFIG_DR_64SPS);
    ads.setGain(ADS1115_REG_CONFIG_PGA_2_048V);
    if( !ads.triggerContinuous() )
    {
        ads1115_pending_mode = ADS1115_MODE_CURRENT;
        return true;
    }
    return false;
}


/**
 * set ADS1115 to continuous Ampere sampling
 * 
 * ACPL-C870 isolates & converts a VIn 1:1 to a differential between AIN0<->AIN1:
 * * max differential = 2.0V (max values of ACPL)
 * * min differential = 0.0V
 * 
 * Voltage calculation is using a Voltage divider of (ideally) 2.010 MOhm ./. 4k7 Ohm
 * ---> Vout = Vin * 4700 / (2010000 + 4700)
 * ---> Vin = Vout / (4700 / (2010000 + 4700))
 * ---> Vin = Vout * (2010000 + 4700) / 4700
 * ---> 850V ^= 1.98292V
*/
bool ads1115_setupVoltageSampling()
{
    // differential AIN2<->AIN3
    ads.setMux(ADS1115_REG_CONFIG_MUX_DIFF_0_1);
    ads.setSampleRate(ADS1115_REG_CONFIG_DR_128SPS);
    ads.setGain(ADS1115_REG_CONFIG_PGA_2_048V);
    if( !ads.triggerContinuous() )
    {
        ads1115_pending_mode = ADS1115_MODE_VOLTAGE;
        return true;
    }
    return false;
}

void ads1115_isr()
{
    ads1115_rdy = true;
}
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
